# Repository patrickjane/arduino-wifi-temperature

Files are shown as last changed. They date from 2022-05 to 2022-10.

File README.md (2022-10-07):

# Overview

This project implements a temperature/humidity sensor using simple components, and even integrates into your smart home. It is highly configurable, and components can also be swapped to your liking, in case you have different components lying around already.

The version I have built for myself is used for my spider enclosure, and I am using the Bosch BME280 sensor along with a NodeMCU microcontroller. 

Optionally, you can configure WiFi-credentials, in which case the sensor will enable NTP time synchronization, so you will be able to set a day/night time (without network access, Arduinos will be unable to know the time of day). In addition, in case you are running a MQTT broker in your network, you can configure the sensor to connect to it. In this case, it will periodically send messages to the MQTT broker containing the temperature/humidity reading. This makes it extremely easy to integrate into your Home Assistant or other smart home software.

This repository also contains .STL files so you can 3D-print a case matching the components I have used.

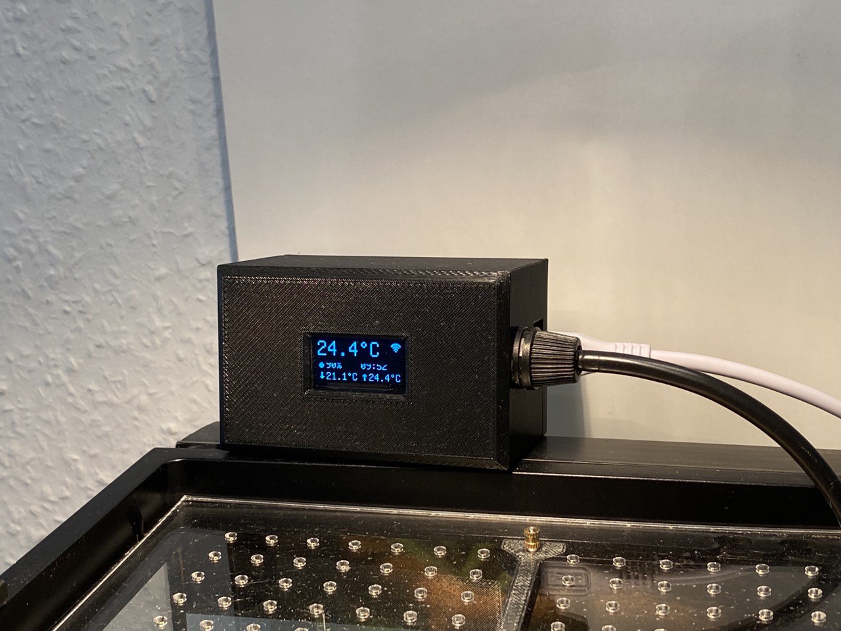
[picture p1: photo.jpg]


# Shopping list

- Microcontroller, preferably [NodeMCU](https://www.amazon.de/AZDelivery-NodeMCU-ESP8266-ESP-12E-Development/dp/B06Y1LZLLY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), 6.99€. Note that the case I am using is designed for a microcontroller with 48x26mm dimensions.
- Temperature sensor, BME280 or DS18B20, e.g. [BME280](https://www.amazon.de/AZDelivery-GY-BME280-Barometrischer-Temperatur-Luftfeuchtigkeit/dp/B07D8T4HP6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), 17.99€. For the BME280 make sure you buy the I2C version
- OLED Display SSD1306, e.g. [OLED Display](https://www.ebay.de/itm/255283295122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), 4.85€. The case is designed for a display with 26x26mm dimensions. Take care, as several different versions of this display are sold with slightly different dimensions
- Cables, screws
- Cable holder/mount for the sensor cable
- Might want to know how to solder

The case I am using for the BME280 sensor is this one: [Sensor case](https://www.thingiverse.com/thing:3809818#Print%20Settings).

# Wiring

Depending on the temperature sensor which is used, the wiring is different.

## BME280 wiring

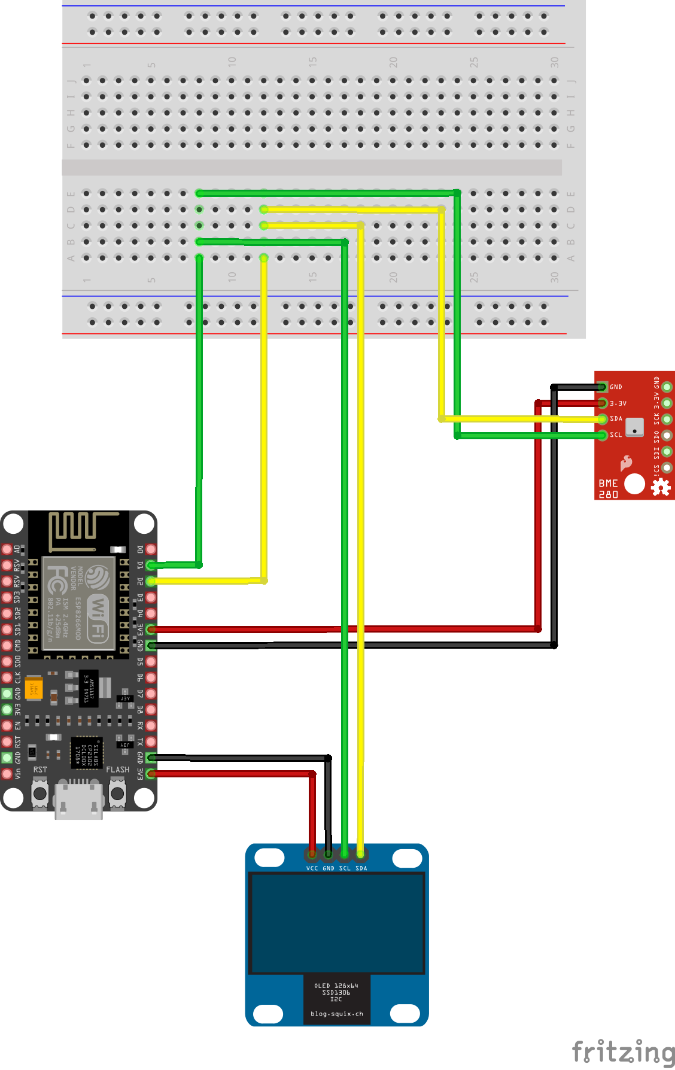
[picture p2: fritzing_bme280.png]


## DS18B20 wiring

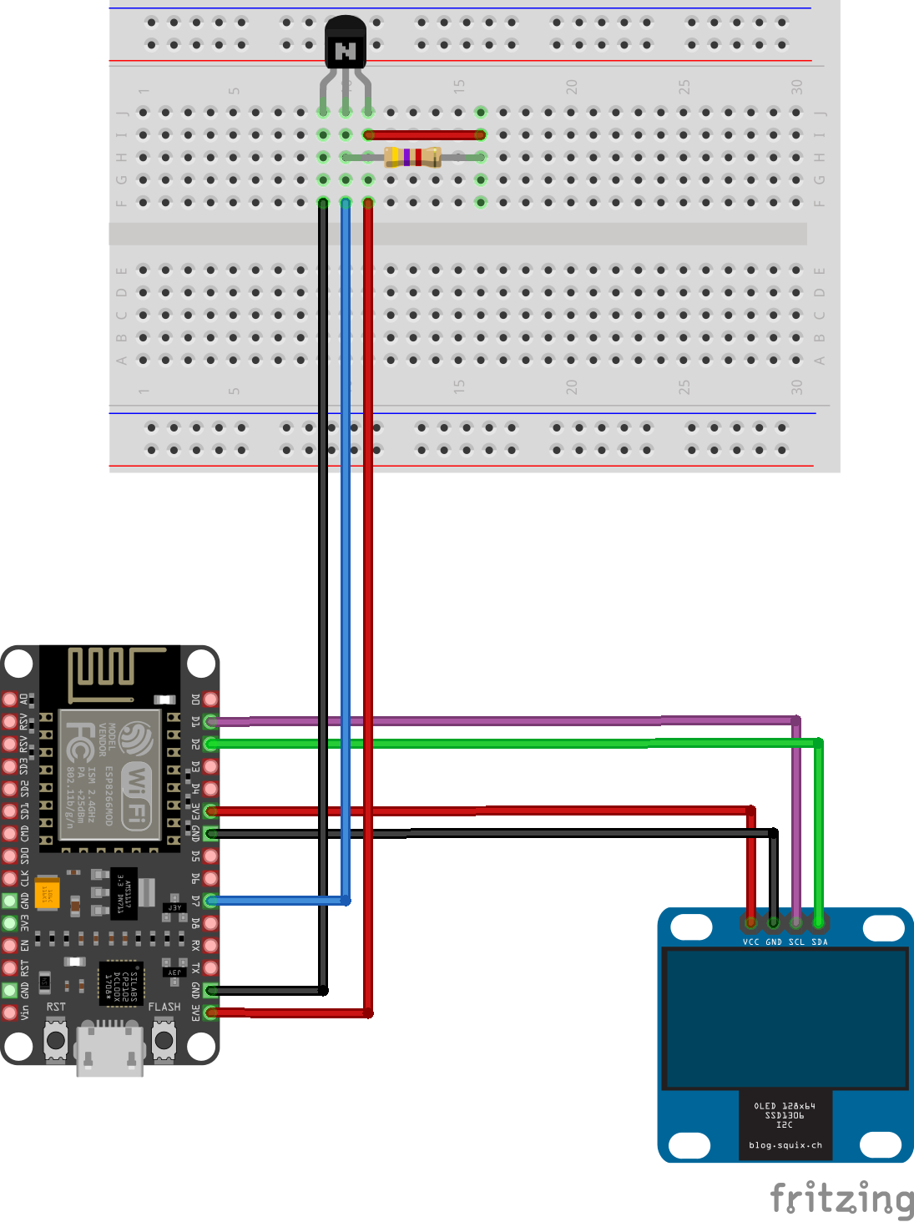
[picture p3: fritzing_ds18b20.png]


# Configuration

When downloading the repo, rename the contained `config_example.h` file to `config.h` before compiling. Make any necessary adjustments to the `config.h` file for your liking. WiFi/MQTT can be completely disabled. In this case, the temperature is only displayed on the display.

All lines starting with `//` will be ignored. So you enable a line by removing the `//` in front of it, and you disable a line by adding `//` in front of it.

## Select microcontroller

```
//#define USE_ESP32            // use THIS line when using Sparkfun Thing ESP32 / Firebeetle ESP32 / Weemos LOLIN 32 lite ...
#define USE_ESP8266          // use THIS line when using NodeMCU / Firebeetle ESP8266
//#define USE_UNO              // use THIS line when using Arduino Uno wifi
```

Select the correct microcontroller you are using. I recommend NodeMCU (`#define USE_ESP8266`). Depending on the board you chose, it might be that code adjustments are necessary, because e.g. EEPROM and WiFi implementations are different from controller to controller. I have tested and can confirm that NodeMCU works fine. 

## Sensor settings

```
#define USE_BOSCH_TEMP          // use THIS line when using BME280 temperature/humidity sensor
//#define USE_DALLAS_TEMP         // use THIS line when using DS18B20 temperature sensor

#define SENSOR_ADDRESS 0x76     // default for BME280, check data sheet

#define MEASURE_EVERY_SECONDS  120 * 1000      // measure every 120s
#define TEMP_SENSOR_PIN        13              // read pin for DS18B20 temperature sensor
                                               // unused if using BOSCH BME280 temperature sensor (will use I2C)
```

The first two lines again select the type of sensor you are using. You must chose one of the two.

When using the BOSCH sensor, `SENSOR_ADDRESS` must be enabled too. You can check the datasheet of the sensor you bought, but the value of `0x76` should be correct. 

When using the DS18B20 sensor, `SENSOR_ADDRESS` is unused. Instead, `TEMP_SENSOR_PIN` must be enabled, and define the pin where the data wire of the sensor is connected.

Finally, `MEASURE_EVERY_SECONDS` defines the interval in which temperature readings are taken. This is also the interval in which readings are published to MQTT.

## WiFi settings

```
#define WIFI_ENABLED

#define WIFI_PASS    "MY_WIFI_SSID"
#define WIFI_SSID    "MY_WIFI_PASSWORD"
#define WIFI_NAME    "terr_tempsensor"

#define MQTT_ID      "MY_CLIENT_ID"
#define MQTT_HOST    "MY_MQTT_HOSTNAME"
#define MQTT_PORT    1883

#define TOPIC_STATE    "ha/sensor/tempsensor/status"
#define TOPIC_CONTROL  "ha/sensor/tempsensor/control"

//#define NTP_HOSTNAME   "myNtpHostName"
```

If using WiFi, the first line must be enabled. In addition, the following three lines must be enabled an contain valid credentials for your WiFi network. When starting the sensor, the display will show a blinking WiFi-icon while connecting. When successfully connected, the WiFi-icon will stop to blink.

When using MQTT, set the hostname of the MQTT broker and the port in the following three lines, as well as a client id (just pick a name for your sensor).

The next two lines define the MQTT topics the sensor will use. The `TOPIC_STATE` will be the topic where temperature readings are published to, while `TOPIC_CONTROL` is a topic the sensor will subscribe to. You can send messages to the control topic in order to change the sensor configuration.

The last line is optional. In case you are running a NTP server in your network, set its hostname here. Otherwise the sensor will try to use public NTP servers. In this case, internet access is needed.

When the sensor starts for the first time, a random device ID is generated and stored in the EEPROM of the microcontroller. This helps to identify your sensor, and it is added to the topic names you defined in `config.h`. This means in the example above, that when for example, the device ID is `0x43ff863d`, the state topic will *actually* be `ha/sensor/tempsensor/status/0x43ff863d`, and the control topic will *actually* be `ha/sensor/tempsensor/control/0x43ff863d`.

### MQTT control messages

Two different commands can be sent to the sensor:

1) Set night mode
   Sets the time slot where the display should be turned off
2) Display
   Enables/disables the display
   
This allows you to have the screen automatically go dark in the night, or to triggere display on/off from your home automation.

#### Set night mode

Send one of the following messages to the control topic:

```
mosquitto_pub -h [MQTT HOSTNAME HERE] -t 'ha/sensor/tempsensor/control/0x43ff863d' -m '{"command":"setNightMode","off":true}' 
mosquitto_pub -h [MQTT HOSTNAME HERE] -t 'ha/sensor/tempsensor/control/0x43ff863d' -m '{"command":"setNightMode","from":"07:15","to":"22:50"}' 
```

The first message completely disables night mode. This means the display will be on 24h hours a day.
The second message lets the display go dark after 22:50 and enable the display again at 7:15 in the morning.

Sending this command overwrites the hardcoded settings from `config.h` (see chapter **Display settings**). Settings here will be saved to the EEPROM and restored after restart.

#### Display

Send one of the following messages to the control topic:

```
mosquitto_pub -h [MQTT HOSTNAME HERE] -t 'ha/sensor/tempsensor/control/0x43ff863d' -m '{"command":"display","off":true}' 
mosquitto_pub -h [MQTT HOSTNAME HERE] -t 'ha/sensor/tempsensor/control/0x43ff863d' -m '{"command":"display","off":false}' 
```

The first message turns on the display, the second one turns it off.

## Display settings

```
#define SCREEN_WIDTH           128      // OLED display width, in pixels
#define SCREEN_HEIGHT          64       // OLED display height, in pixels
#define OLED_RESET             -1       // Reset pin # (or -1 if sharing Arduino reset pin)
#define SCREEN_ADDRESS         0x3C     //< See datasheet for Address

#define DISPLAY_START          "07:15"  // turn on display
#define DISPLAY_END            "22:00"  // turn off display
```

The first two lines define the display dimensions, and the third line defines the reset pin. Should be left at -1 to use the arduino reset button. The screen address can be taken from the display datasheet, but `0x3C` will most likely work.

The last two lines define the time during which the display is enabled. Outside of this timeframe the display will go dark. If you disable both lines, the display will be on 24h a day.
The display can also be turned on/off via MQTT commands, see chapter **MQTT control messages**.

# Home assistant integration

Just add the following to your `configuration.yaml`: 

```
sensor:
  - platform: mqtt
    state_topic: 'ha/sensor/tempsensor/status/0x43ff863d'
    json_attributes_topic: 'ha/sensor/tempsensor/status/0x43ff863d'
    value_template: '{{value_json.temperature}}'
    name: "Terrarium Temperature"
    unit_of_measurement: '°C'
    
  - platform: mqtt
    state_topic: 'ha/sensor/tempsensor/status/0x43ff863d'
    json_attributes_topic: 'ha/sensor/tempsensor/status/0x43ff863d'
    value_template: '{{value_json.humidity}}'
    name: "Terrarium Humidity"
    unit_of_measurement: '%'
```

The second sensor can be of course omitted when using the DS18B20 sensor, since it does not provide humidity readins.

Of course, you're `configuration.yaml` needs to have the same MQTT broker configured you set in the `config.h` file.

# Sensor case

The files `case.STL` and `case_lid.STL` contain the parts which can be 3D printed to make a case for the sensor. The case was designed by Thomas Kleinknecht.

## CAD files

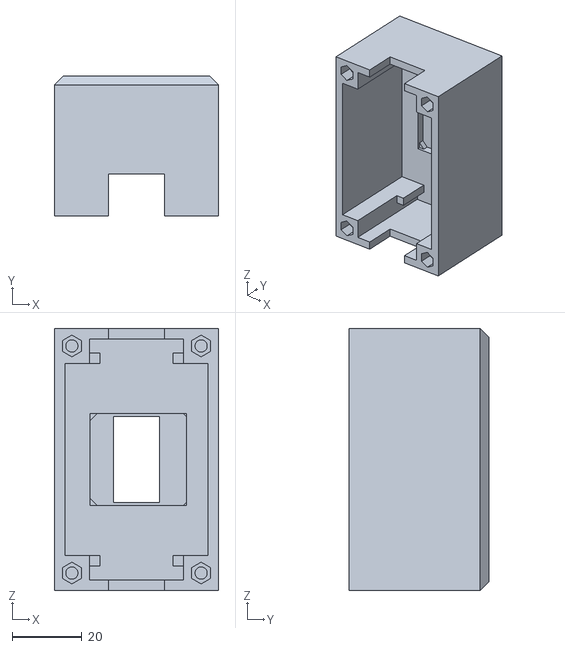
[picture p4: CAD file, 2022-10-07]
case.STL
47.0 x 40.0 x 75.0

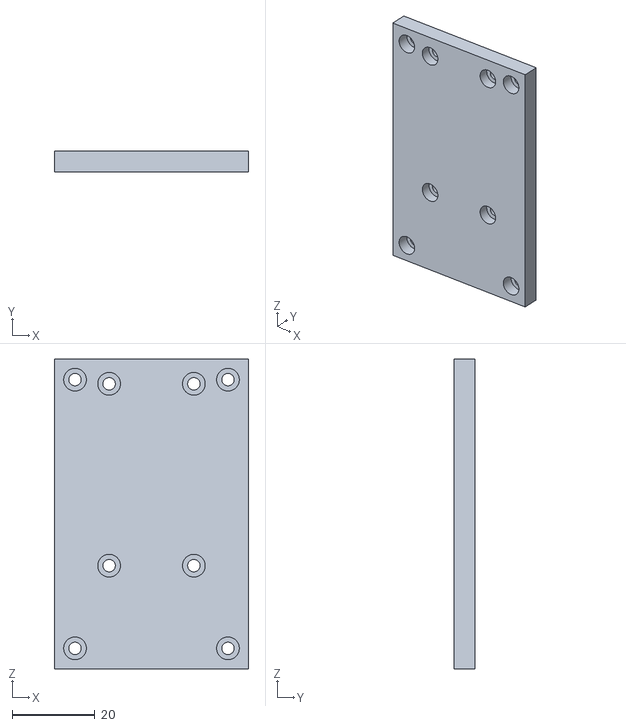
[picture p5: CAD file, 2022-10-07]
case_lid.STL
47.0 x 5.00 x 75.0

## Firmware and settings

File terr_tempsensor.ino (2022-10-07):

// ************************************************************************************
// IoT / MQTT ultrasonic sensor
// ************************************************************************************
// ************************************************************************************
// sunsensor.ino
// ************************************************************************************
// Copyright (c) 2021 - Patrick Fial
// ************************************************************************************

// ************************************************************************************
// Includes
// ************************************************************************************

#include <MQTT.h>
#include <SPI.h>
#include <Wire.h>
#include <Adafruit_GFX.h>
#include <Adafruit_SSD1306.h>
#include <time.h>

#include "NTP.h"

#include "config.h"
#include "icons.h"
#include "eeprom.hpp"

#if defined(USE_UNO)
  #include <WiFiNINA.h>
#elif defined(USE_ESP8266)
  #include <ESP8266WiFi.h>
#else
  #include <WiFi.h>
#endif

#if defined(USE_BOSCH_TEMP)
  #include <Adafruit_Sensor.h>
  #include <Adafruit_BME280.h>
#elif defined(USE_DALLAS_TEMP)
  #include <OneWire.h>
  #include <USE_DALLAS_TEMPTemperature.h>
#endif

#include "WiFiUdp.h"

// ************************************************************************************
// Globals
// ************************************************************************************

WiFiClient wifiClient;
MQTTClient client;
Eeprom eeprom;
WiFiUDP wifiUdp;
NTP ntp(wifiUdp);

#if defined(USE_BOSCH_TEMP)
  Adafruit_BME280 bme; // I2C
#elif defined(USE_DALLAS_TEMP)
  OneWire oneWire(TEMP_SENSOR_PIN);
  USE_DALLAS_TEMPTemperature sensors(&oneWire);
#endif

Adafruit_SSD1306 display(SCREEN_WIDTH, SCREEN_HEIGHT, &Wire, OLED_RESET);

short wifiIconStep = 0;
unsigned short sensorErrors = 0;
bool nightMode = false;
time_t displayStart = 0;
time_t displayEnd = 0;
struct tm timeStruct;
bool connected = false;
bool sensorError = false;
char buffer[100+1];
char deviceIdText[30+1];
char currentTimeString[7];
unsigned long deviceID = 0;
unsigned long lastMeasure = 0;
float lastTemperatureValue = 0.0;
float minTemperatureValue = 0.0;
float maxTemperatureValue = 0.0;
float lastHumidityValue = 0.0;
bool reInitMinMax = true;
short currentDayNum = -1;

// ************************************************************************************
// Functions
// ************************************************************************************

void connectMQTT();
void disconnectMQTT();
bool connectWIFI();
void disconnectWIFI();

void doMeasure();
bool updateMQTT();
void updateDisplay(int wifiNum = -1);
void setNightMode(unsigned long fromHour, unsigned long fromMinute, unsigned long toHour, unsigned long toMinute);
void setNightMode(const char* from, const char* to, bool saveToEeprom, bool off = false);

// ************************************************************************************
// Setup
// ************************************************************************************

void setup()
{
#ifdef SS_DEBUG
  Serial.begin(9600);
  while (!Serial) {
    ; // wait for serial port to connect. Needed for native USB
  }
#endif

  PRINTLN("Init display");

  if (!display.begin(SSD1306_SWITCHCAPVCC, SCREEN_ADDRESS)) {
    PRINTLN(F("SSD1306 allocation failed"));
    for(;;); // Don't proceed, loop forever
  }

  memset(currentTimeString, 0, sizeof(currentTimeString));

  PRINTLN("Starting temperature sensor");

#ifdef USE_BOSCH_TEMP
  bool status = bme.begin(SENSOR_ADDRESS);
  
  if (!status) {
    Serial.println("Could not find a valid BME280 sensor, check wiring!");
    while (1);
  }
#endif

#ifdef USE_DALLAS_TEMP
  sensors.begin();
#endif

  display.display();
  display.setTextColor(WHITE);
  display.ssd1306_command(SSD1306_SETCONTRAST); 
  display.ssd1306_command(1);
  delay(2000);

  eeprom.begin();
  
  if (eeprom.isInitialized())
  {
    deviceID = eeprom.getValue(eiDeviceID);
    PRINTF("Read device ID 0x%x from EEPROM\n", deviceID);

    unsigned long fromHour = eeprom.getValue(eiNightModeStartHour);
    unsigned long fromMinute = eeprom.getValue(eiNightModeStartMinute);
    unsigned long toHour = eeprom.getValue(eiNightModeEndHour);
    unsigned long toMinute = eeprom.getValue(eiNightModeEndMinute);

    if (fromHour < 30)
    {
      setNightMode(fromHour, fromMinute, toHour, toMinute);
    }
#if defined(DISPLAY_START) && defined(DISPLAY_END)
    else if (fromHour != 777)
    {
      setNightMode(DISPLAY_START, DISPLAY_END, false);
    }
#endif    
  }
  else
  {
    PRINTLN("Initializing EEPROM");
    deviceID = random(2147483646);
    eeprom.setCookie();
    eeprom.setValue(eiDeviceID, deviceID);

#if defined(DISPLAY_START) && defined(DISPLAY_END)
    setNightMode(DISPLAY_START, DISPLAY_END, true);
#else
    eeprom.setValue(eiNightModeStartHour, 100);
    eeprom.setValue(eiNightModeStartMinute, 100);
    eeprom.setValue(eiNightModeEndHour, 100);
    eeprom.setValue(eiNightModeEndMinute, 100);
#endif

    eeprom.commit();
  }

  sprintf(deviceIdText, "ID: 0x%x\n", deviceID);

  display.clearDisplay();
  display.setTextSize(1);
  display.setCursor(0, 0);
  display.printlnUTF8(deviceIdText);
  display.display();
  delay(2000);

#if !defined(USE_UNO) && !defined(USE_ESP8266)
  char nameBuf[50];
  snprintf(nameBuf, 50, "%s-0x%x", WIFI_NAME, deviceID);
  WiFi.setHostname(nameBuf);
#endif

  client.begin(MQTT_HOST, MQTT_PORT, wifiClient);
  client.setOptions(0, true, 360000);
#ifdef TOPIC_CONTROL  
  client.onMessageAdvanced(onMessageReceived);
#endif

  PRINTLN("Starting NTP client");
  ntp.ruleDST("CEST", Last, Sun, Mar, 2, 120); // last sunday in march 2:00, timetone +120min (+1 GMT + 1h summertime offset)
  ntp.ruleSTD("CET", Last, Sun, Oct, 3, 60); // last sunday in october 3:00, timezone +60min (+1 GMT)

#ifdef NTP_HOSTNAME  
  ntp.begin(NTP_HOSTNAME);
#else
  ntp.begin();
#endif
  
  PRINTLN("UP");
}

// ************************************************************************************
// loop
// ************************************************************************************

void loop()
{
  static int lastMinute = -1;

  if (!lastMeasure || (millis() - lastMeasure) >= MEASURE_EVERY_SECONDS)
  {
    lastMeasure = millis();
    doMeasure();

#ifdef WIFI_ENABLED
    ntp.update();
#endif
  }

#ifdef WIFI_ENABLED
  if (!connected)
  {
    bool succeeded = connect();

    if (!succeeded)
    {
      PRINTLN("Wifi connect failed, skipping NTP update/MQTT update");
      return;
    }
  }

  client.loop();
  delay(250);

  int dayNum = ntp.day();

  if (currentDayNum == -1 || currentDayNum != dayNum)
  {
    currentDayNum = dayNum;
    minTemperatureValue = 0.0;
    maxTemperatureValue = 0.0;
    reInitMinMax = true;
  }

  timeStruct.tm_hour = ntp.hours();
  timeStruct.tm_min = ntp.minutes();
  time_t nowTime = mktime(&timeStruct);

  snprintf(currentTimeString, 6, "%0.2d:%0.2d", ntp.hours(), ntp.minutes());

  if (lastMinute != ntp.minutes())
  {
    updateDisplay();
    lastMinute = ntp.minutes();
  }
  
  bool nightModeNow = displayStart != 0 && !(nowTime >= displayStart && nowTime < displayEnd);

  if (nightModeNow != nightMode)
  {
    if (nightModeNow)
      display.dim(true);
    else
      display.dim(false);

    nightMode = nightModeNow;
    
    PRINTF("Night mode switched to: %s\n", nightMode ? "on" : "off");
  }      

  if (!client.connected()) {
    PRINTLN("MQTT client lost connection, disconnecting WiFi and trying to reconnect ...");
    disconnect();
    delay(2000);
    connect();
  }
#endif
}

// ************************************************************************************
// connect/disconnect WIFI+MQTT
// ************************************************************************************

bool connect()
{
#ifdef WIFI_ENABLED  
  bool res = connectWIFI();

  if (!res)
    return res;

  ntp.update();
  connectMQTT();
  updateDisplay();
#endif
  return true;
}

void disconnect()
{
#ifdef WIFI_ENABLED
  disconnectMQTT(); 
  disconnectWIFI();
  updateDisplay();
#endif
}

const char* status2Text(int status)
{
  switch (status)
  {
    case WL_IDLE_STATUS:     return "WL_IDLE_STATUS";
    case WL_NO_SSID_AVAIL:   return "WL_NO_SSID_AVAIL";
    case WL_SCAN_COMPLETED:  return "WL_SCAN_COMPLETED";
    case WL_CONNECTED:       return "WL_CONNECTED";
    case WL_CONNECT_FAILED:  return "WL_CONNECT_FAILED";
    case WL_CONNECTION_LOST: return "WL_CONNECTION_LOST";
    case WL_DISCONNECTED:    return "WL_DISCONNECTED";
    case WL_NO_SHIELD:       return "WL_NO_SHIELD";
    default: break;
  }

  snprintf(buffer, 100, "Unknown (%d)", status);

  return buffer;
}

// ************************************************************************************
// connect/disconnect WIFI
// ************************************************************************************

bool connectWIFI()
{
#ifdef WIFI_ENABLED
  PRINTF("[WIFI] Connecting to network %s ...", WIFI_SSID);

  WiFi.begin(WIFI_SSID, WIFI_PASS);

  int tries = 0;
  static const int maxTries = 600;

  while (WiFi.status() != WL_CONNECTED) 
  {
    if (tries++ >= maxTries)
    {
        PRINTF("\n[WIFI] Giving up after %d tries \n", maxTries);
        return false;
    }

    updateDisplay(wifiIconStep++);
    PRINT(".");
    delay(400);
  }

  PRINTLN(" connected");
#endif
  return true;
}

void disconnectWIFI()
{
#ifdef WIFI_ENABLED
  PRINTF("[WIFI] Disconnecting to network %s ...\n", WIFI_SSID);
  WiFi.disconnect();
  PRINTLN("[WIFI] Disconnected");
  connected = false;
#endif
}

// ************************************************************************************
// connect/disconnect MQTT
// ************************************************************************************

void connectMQTT() 
{
#ifdef WIFI_ENABLED
  PRINTF("[MQTT] Connecting to host %s ...", MQTT_HOST);

  while (!client.connect(MQTT_ID)) 
  {
    PRINT(".");
    updateDisplay(wifiIconStep++);
    delay(400);
  }

  PRINTLN(" connected");  

#ifdef TOPIC_CONTROL
  char topicBuffer[200];
  snprintf(topicBuffer, 200, "%s/0x%x", TOPIC_CONTROL, deviceID);
  
  PRINTF("[MQTT] Subscribing to control topic %s ...\n", topicBuffer);
  
  if (!client.subscribe(topicBuffer))
  {
    PRINT(".");
    updateDisplay(wifiIconStep++);
    delay(400);
  }  
#endif

  connected = true;
#endif
}

void disconnectMQTT()
{
#ifdef WIFI_ENABLED
  PRINTF("[MQTT] Disonnecting from host %s ...\n", MQTT_HOST);
  client.disconnect();
  PRINTLN("[MQTT] Disconnected");
  connected = false;
#endif
}

// ************************************************************************************
// doMeasure
// ************************************************************************************

void doMeasure()
{
  float hum = 0.0;
  float tempC = 0.0;
  bool hadSensorError = sensorError;

  sensorError = false;
  
#ifdef USE_BOSCH_TEMP
  tempC = bme.readTemperature();
  hum = bme.readHumidity();

  if (isnan(tempC) || isnan(hum))
  {
    if (!hadSensorError)
      sensorErrors++;

    sensorError = true;
    updateDisplay();
    PRINTLN("Error: Could not read temperature data");
    return;
  }
#endif

#ifdef USE_DALLAS_TEMP
  sensors.requestTemperatures();

  tempC = sensors.getTempCByIndex(0);
 
  // Check if reading was successful
 
  if (tempC == DEVICE_DISCONNECTED_C) 
  {
    if (!hadSensorError)
      sensorErrors++;
    
    sensorError = true;
    updateDisplay();
    PRINTLN("Error: Could not read temperature data");
    return;
  }
#endif

  lastTemperatureValue = tempC;
  lastHumidityValue = hum;

  if (reInitMinMax || lastTemperatureValue < minTemperatureValue)
    minTemperatureValue = lastTemperatureValue;

  if (reInitMinMax || lastTemperatureValue > maxTemperatureValue)
    maxTemperatureValue = lastTemperatureValue;

  reInitMinMax = false;

  updateDisplay();
  updateMQTT();
}

// ************************************************************************************
// updateDisplay
// ************************************************************************************

void updateDisplay(int wifiNum)
{
  display.clearDisplay();
  display.setTextSize(2.0);
  display.setTextColor(WHITE);
  display.setCursor(0,0);
  sprintf(buffer, "%2.1f°C", lastTemperatureValue);
  display.printlnUTF8(buffer);

  if (wifiNum >= 0)
  {
    int _wifiNum = (wifiNum % 3 + 1);
  
    switch (_wifiNum)
    {
      case 1: display.drawBitmap(128-16, 8, wifi1_icon16x16, 16, 16, SSD1306_WHITE); break;
      case 2: display.drawBitmap(128-16, 8, wifi2_icon16x16, 16, 16, SSD1306_WHITE); break;
      case 3: display.drawBitmap(128-16, 8, wifi3_icon16x16, 16, 16, SSD1306_WHITE); break;
      default: break;
    }
  } 
  else if (connected)
  {
    display.drawBitmap(128-16, 8, wifi3_icon16x16, 16, 16, SSD1306_WHITE);
  }

  if (sensorError) 
  {
    display.drawBitmap(128-16, 28, noconnection_icon16x16, 16, 16, SSD1306_WHITE);
  }
    
  int xpos = 0;
  int ypos = 32;

#ifdef USE_BOSCH_TEMP
  display.drawBitmap(xpos, ypos+1, drop_icon16x16, 16, 16, SSD1306_WHITE);
  xpos += 14;
  display.setTextSize(1);
  display.setCursor(xpos, ypos);
  sprintf(buffer, "%.0f%%", lastHumidityValue);
  display.printlnUTF8(buffer);
#endif

  if (strlen(currentTimeString))
  {
    xpos += 53;
    display.setTextSize(1);
    display.setCursor(xpos, ypos);
    display.printlnUTF8(currentTimeString);
  }
  
  xpos = 0;
  ypos = 48;
  display.drawBitmap(xpos, ypos+1, arrow_down_icon16x16, 16, 16, SSD1306_WHITE);
  xpos += 14;
  display.setTextSize(1);
  display.setCursor(xpos, ypos);
  sprintf(buffer, "%2.1f°C", minTemperatureValue);
  display.printlnUTF8(buffer);
  
  xpos += 51;
  display.drawBitmap(xpos, ypos+1, arrow_up_icon16x16, 16, 16, SSD1306_WHITE);
  xpos += 14;
  display.setCursor(xpos, ypos );
  sprintf(buffer, "%2.1f°C", maxTemperatureValue);
  display.printlnUTF8(buffer);
  display.display();
}

// ************************************************************************************
// updateMQTT
// ************************************************************************************

bool updateMQTT()
{
  bool res = true;

#ifdef WIFI_ENABLED
  if (!connected)
    return res;
  
  char topicBuffer[200];

#if defined(USE_BOSCH_TEMP)
  snprintf(buffer, 100, "{ \"temperature\": %2.2f, \"humidity\": %2.2f, \"errors\": %d }", lastTemperatureValue, lastHumidityValue, sensorErrors);
#elif defined(USE_DALLAS_TEMP)
  snprintf(buffer, 100, "{ \"temperature\": %2.2f, \"errors\": %d }", lastTemperatureValue, sensorErrors);
#endif

  snprintf(topicBuffer, 100, "%s/0x%x", TOPIC_STATE, deviceID);

  res = client.publish(topicBuffer, buffer, false, 0);

  if (!res)
    PRINTLN("Failed to publish new sensor value");
  else
    PRINTF("-> %s [%s]\n", topicBuffer, buffer);
#endif

  return res;
}

// ************************************************************************************
// onMessageReceived
// ************************************************************************************

void onMessageReceived(MQTTClient* client, char* topic, char* payload, int payload_length) 
{
  char topicBuffer[200];
  snprintf(topicBuffer, 200, "%s/0x%x", TOPIC_CONTROL, deviceID);
    
  if (strcmp(topic ? topic : "", topicBuffer))
  {
    PRINTF("Ignoring message for unexpected topic %s\n", topic ? topic : "");
    return;
  }
  
  if (!payload || !*payload)
  {
    PRINTF("Ignoring message without payload\n");
    return;
  }

  char command[30+1]; *command = 0;

  if (!getJsonValue(payload, "command", command, 30))
  {
    PRINTF("Ignoring message without 'command' property\n");
    return;
  }

  if (!strcmp(command, "setNightMode"))
  {
    char from[10]; *from= 0;
    char to[10]; *to= 0;
    char off[10]; *off= 0;    

    if (!getJsonValue(payload, "from", from, 10) && !getJsonValue(payload, "off", off, 10))
    {
      PRINTF("Ignoring setNightMode message without 'from'/'off' property\n");
      return;
    }

    if (!strcmp(off, "true"))
    {
      setNightMode("", "", true, true);
      eeprom.commit();
      return;
    }

    if (!getJsonValue(payload, "to", to, 10))
    {
      PRINTF("Ignoring setNightMode message without 'to' property\n");
      return;
    }

    setNightMode(from, to, true);
    eeprom.commit();
  }

  if (!strcmp(command, "display"))
  {
    char off[10]; *off= 0;    

    if (!getJsonValue(payload, "off", off, 10))
    {
      PRINTF("Ignoring display message without 'off' property\n");
      return;
    }

    if (!strcmp(off, "true"))
      display.dim(true);
    else
      display.dim(false);
  }  
}

// ************************************************************************************
// setNightMode
// ************************************************************************************

void setNightMode(const char* from, const char* to, bool saveToEeprom, bool off)
{
  if (off)
  {
    if (saveToEeprom)
    {
      eeprom.setValue(eiNightModeStartHour, 777);
      eeprom.setValue(eiNightModeStartMinute, 777);
      eeprom.setValue(eiNightModeEndHour, 777);
      eeprom.setValue(eiNightModeEndMinute, 777);
      displayStart = displayEnd = 0;

      PRINTF("Display now always on\n");
    }
    
    return;  
  }
  
  if (!from || !*from || !to || !*to || strlen(from) != 5 || strlen(to) != 5)
    return;
    
  char buf1[50];
  char buf2[50];

  memset(&timeStruct, 0, sizeof(struct tm));

  timeStruct.tm_hour = atoi(from);
  timeStruct.tm_min = atoi(from+3);
  displayStart = mktime(&timeStruct);

  if (saveToEeprom)
  {
    eeprom.setValue(eiNightModeStartHour, timeStruct.tm_hour);
    eeprom.setValue(eiNightModeStartMinute, timeStruct.tm_min);
  }

  strftime(buf1, 50, "%R", &timeStruct);  

  timeStruct.tm_hour = atoi(to);
  timeStruct.tm_min = atoi(to+3);
  displayEnd = mktime(&timeStruct);

  if (saveToEeprom)
  {
    eeprom.setValue(eiNightModeEndHour, timeStruct.tm_hour);
    eeprom.setValue(eiNightModeEndMinute, timeStruct.tm_min);
  }

  strftime(buf2, 50, "%R", &timeStruct);  

  PRINTF("Display on between %s - %s\n", buf1, buf2);
}

void setNightMode(unsigned long fromHour, unsigned long fromMinute, unsigned long toHour, unsigned long toMinute)
{
  char buf1[50];
  char buf2[50];

  memset(&timeStruct, 0, sizeof(struct tm));

  timeStruct.tm_hour = fromHour;
  timeStruct.tm_min = fromMinute;
  displayStart = mktime(&timeStruct);

  strftime(buf1, 50, "%R", &timeStruct);  

  timeStruct.tm_hour = toHour;
  timeStruct.tm_min = toMinute;
  displayEnd = mktime(&timeStruct);

  strftime(buf2, 50, "%R", &timeStruct);  

  PRINTF("Display on between %s - %s (e)\n", buf1, buf2);
}

// ************************************************************************************
// getJsonValue
// ************************************************************************************

bool getJsonValue(const char* source, const char* property, char* dest, int destLen)
{
  if (!source || !strlen(source))
    return false;

  char* p = strstr(source, property);
  char* p2;

  if (!p)
    return false;

  p += strlen(property);

  while (*p && (*p == ' ' ||  *p == ':' || *p == '"'))
    p++;

  if (!(*p))
    return false;

  bool isString = *(p-1) == '"';
  p2 = p;

  if (isString)
  {
    while (*p && (*p != '"' || *(p-1) == '\\'))
      p++;
  }
  else
  {
    while (*p && *p != ',' && *p != ' ' && *p != '}' && *p != ']')
      p++;
  }

  if (!(*p))
    return false;

  int valueLen = p - p2;

  if (valueLen > 0 && valueLen < destLen+1)
  {
    strncpy(dest, p2, valueLen);
    dest[valueLen] = 0;
    return true;
  }

  return false;
}
